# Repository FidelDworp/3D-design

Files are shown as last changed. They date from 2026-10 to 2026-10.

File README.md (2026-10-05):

# 3D-design
Ontwerp van 3D objecten in samenwerking met Claude.ai etc...

1) ROOMSENSE CAP: Kapje op de Roomsense PCB. Aaangepast aan de nieuwe 3v3 PIR sensor: Kleinere diameter, excentrisch.

Prijs gevraagd in geraardsbergen bij https://www.dilima.be/3dprint.

Offerte aangevraagd op 5 oct 26 aan: serge@dilima.be

"Hoi, ik ben Filip uit Zarlardinge en wil graag een kleine reeks 3D objecten laten maken.
Daarom graag een prijs voor dit ontwerp:

RoomSense_cap.stl

Keuzes:

- Materiaal: PETG, PLA of PLA+ (5 in ZWART, 5 in WIT)
- Laaghoogte 0,2 mm
- Printen met de rand op het bed
- Tree supports binnenin.

Laat je mij weten als je nog extra info nodig hebt aub?

Vooraf bedankt!
Filip Delannoy
0477743888"

2) ESP32_shield_cap: Het kapje is een rechthoekige doos zonder bodem. Het dekt de ESP32-C6 ZARLAR shield af, die met 4 hoekschroeven rechtstreeks op een plankje vastzit. De rand van het kapje zakt tot op het plankje. Het kapje klikt vast met taps toelopende klemnokjes op de PCB-rand en heeft geen eigen schroeven nodig.

Doorvoeren: alle doorvoeren voor kabels zitten in de zijwanden, als sleuven die onderaan open zijn. Je kunt het kapje dus over de aangesloten kabels schuiven.
Antenne: de antenne van de ESP32 steekt door een sleuf in de bovenwand naar buiten, zodat de behuizing het signaal niet hindert.
Dak: het dak is dicht, met het iTroniX-logo en de naam 0,6 mm verzonken.

3)

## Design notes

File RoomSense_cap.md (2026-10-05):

# RoomSense-kapje – ontwerpdocumentatie

| | |
|---|---|
| **Onderdeel** | 3D-geprint afdekkapje voor de RoomSenseboX v3.0 PCB (iTroniX) |
| **Versie** | v1.4 – 2026-10-05 |
| **Bronbestand** | `RoomSense_cap.scad` (OpenSCAD, volledig parametrisch) |
| **Printbestand** | `RoomSense_cap.stl` (met ingebouwde steunvinnen) |
| **PCB-referentie** | Eagle `RoomsenseboX-v3.0.brd` (export `RoomsenseboX-v3.0-brd-RD-dim.pdf`) |

## 1. Beschrijving

Het kapje dekt de RoomSenseboX-PCB af, die plat tegen het plafond of de muur geschroefd zit. De onderrand van het kapje valt samen met de onderkant van de PCB. Het kapje klemt op de PCB-rand en heeft geen eigen schroeven nodig.

Belangrijkste wijziging t.o.v. het oude (verloren) ontwerp: de grote 5 V **HC-SR501** PIR is vervangen door de kleine 3,3 V **AM312** PIR. Die zit excentrisch, vlak naast de RJ45-connector. Daardoor is de kegel **scheef**: de top met het PIR-plateau ligt boven de AM312. Aan de RJ45-kant loopt de kegel steil af, aan de overkant flauw.

### Onderdelen op de PCB die het kapje bedient

| Onderdeel | Functie in het kapje |
|---|---|
| AM312 PIR | Opening Ø 15 mm in het plateau. De lens steekt erdoor naar buiten. |
| LDR | Lichtopening Ø 10 mm |
| DS18B20-2 | Ventilatierooster Ø 10 mm erboven (luchttemperatuur) |
| DHT22 / AM2302 (T&H) | Eigen vak dat overgaat in de kegel, met een rooster van Ø 10 mm erboven |
| RJ45 | Open tunnel. De stekker blijft in de connector zitten. |
| 4 PCB-montageschroeven | Uitsparingen in de binnenrichel voor de schroefkoppen |

## 2. Assenstelsel

- **Oorsprong:** middelpunt van de PCB.
- **z = 0:** onderkant van de PCB, dus het plafond- of muurvlak.
- **Bovenaanzicht, hoeken (wijzerzin):**

| Hoek | Richting | Onderdeel |
|---|---|---|
| 0° | −Y (onder) | RJ45 |
| 90° | −X (links) | LDR |
| 270° | +X (rechts) | DHT22 |

In de code zet `upos(hoek, straal)` een hoek uit deze conventie om naar XY.

## 3. Afmetingen

### 3.1 PCB (gemeten / uit Eagle)

| Item | Waarde |
|---|---|
| PCB-diameter | 72,0 mm |
| PCB-dikte | 1,75 mm |
| Montagegaten PCB (Ø 3,2) | (27,4 ; 18,8), (−26,8 ; 18,2), (18,5 ; −27,0), (−17,9 ; −27,4), dus R ≈ 33,2 mm |
| RJ45-behuizing (Eagle) | X −8,6 … +7,0 / Y −20,0 … −38,6. Steekt 2,6 mm buiten de PCB-rand. |
| RJ45-breedte (gemeten) | 16,2 mm, midden op X = −0,8 mm |
| RJ45-hoogte incl. PCB | 16 mm |
| PIR-header (3-pin) | midden (−0,4 ; −12,0) |
| PIR-lens AM312 | Ø 12,13 mm, midden op 17,8 mm van het centrum richting RJ45 (staat schuin op de header) |
| LDR | (−26,1 ; 0), dus 90°, R 26,1 |
| DS18B20-2 | (−24,9 ; −16), dus ≈ 57°, R 29,7 |
| DHT22-header (TH) | Y −13, X 21,7 … 29,4 |
| DHT22-voetafdruk | 28 × 18 mm op 270°, symmetrisch t.o.v. de as. Binnenkant op R 15,2, buitenhoeken op de PCB-rand. |
| DHT22-hoogte incl. PCB | 10 mm |

### 3.2 Kapje

| Item | Waarde | Parameter |
|---|---|---|
| Buitendiameter | Ø 80 mm | `outer_d` |
| Wanddikte | 2,0 mm | `wall` |
| Speling (algemeen) | 0,3 mm | `clr` |
| Binnendiameter PCB-kamer | Ø 72,6 mm | `pcb_d + 2·clr` |
| Hoogte verticale rand | 7 mm vanaf onderkant PCB | `skirt_h` |
| Bovenkant plateau | 23 mm boven het PCB-oppervlak (24,75 mm vanaf onderkant) | `top_above` |
| Plateau rond PIR | Ø 21 mm, middelpunt (0 ; −17,8) | `plateau_d`, `pir_ecc` |
| PIR-opening | Ø 15 mm | `pir_hole_d` |
| LDR-opening | Ø 10 mm op 90°, R 26,1 | `ldr_hole_d`, `ldr_ang`, `ldr_r` |
| Rooster DS18B20 | Ø 10 mm op 57°, R 28 | `vent1_ang`, `vent1_r`, `vent_d` |
| Rooster DHT22 | Ø 10 mm op 270°, R 24,2 (midden van het DHT-vak) | `vent2_r` |
| Roostergaatjes | 1,2 × 1,2 mm, steek 2,0 mm | `g_hole`, `g_pitch`, `grille` |
| RJ45-tunnel, inwendig | 16,8 mm breed (16,2 + 2·0,3), 16,3 mm hoog vanaf onderkant PCB | `rj_w`, `rj_h`, `rj_off` |
| RJ45-tunnel, begin | 19,7 mm van het centrum (achterkant connector − speling) | `rj_back` |
| RJ45-tunnel, einde | Gelijk met de buitenrand van het kapje. Open naar buiten voor de stekker. | – |
| DHT22-vak, inwendig | 28,6 × radiaal tot de PCB-rand, 10,5 mm hoog vanaf onderkant PCB | `dht_len`, `dht_w`, `dht_h`, `dht_in` |
| DHT22-vak, buitenkant | Plat dak op 12,5 mm, gaat over in de kegel | – |

### 3.3 Bevestiging (klemmen zonder schroeven)

| Item | Waarde | Parameter |
|---|---|---|
| Binnenrichel | 1,5 mm breed × 1,5 mm hoog. Drukt de PCB tegen het plafond. | `ridge_w`, `ridge_h` |
| Uitsparing schroefkoppen | Ø 7 mm rond elk PCB-montagegat | `screw_head_d` |
| Klemnokjes (crush ribs) | 5 stuks op 55°, 90°, 160°, 200°, 305° | `clip_angles` |
| Profiel nokje | Driehoekig: voet 2,0 mm, punt 0,4 mm | `clip_w`, `clip_tip` |
| Indrukking in de PCB-rand | 0,35 mm | `clip_interf` |
| Invoerschuinte | 1,2 mm hoog vanaf de onderrand | `clip_lead` |

De nokjes vermijden de schroeven, de RJ45 en de hoeken van de DHT22.

### 3.4 Ingebouwde wegbreekbare steunvinnen

Aan de flauwe kant loopt de kegel maar ±20° op. Die binnenkant kan daarom niet zonder steun geprint worden. De steun zit in het model zelf, zodat de slicer **geen** support hoeft toe te voegen.

| Item | Waarde | Parameter |
|---|---|---|
| Aantal vinnen | 16, radiaal vanuit de PIR-top, gelijk verdeeld | `sup_n` |
| Hoekbereik | −40° … 220° (wiskundig, 0° = +X). De steile RJ45-kant blijft vrij. | `sup_from`, `sup_to` |
| Dikte vin | 0,8 mm (2 perimeters) | `sup_t` |
| Start / max. straal | 8 mm rond de PIR-top / 34 mm rond het PCB-midden (vrij van richel en klemnokjes) | `sup_r0`, `sup_rmax` |
| Spleet vin ↔ kegel | 0,3 mm | `sup_gap` |
| Verbinding | Tandjes van 0,8 × 0,8 mm, om de 5 mm langs de vin | `sup_tooth`, `sup_pitch` |
| Verbindingsring op het bed | Straal 14 mm rond de PIR-top, 1,2 mm breed, 0,6 mm hoog. **Raakt het kapje nergens.** | `sup_ring_r`, `sup_ring_w`, `sup_ring_h` |
| Uitgesloten zones | DHT22-vak en RJ45-tunnel | – |
| Aan / uit | `true` | `sup_on` |

**Overspanning:** tussen de vinnen is de overspanning maximaal ±15 mm, aan de buitenrand.

**Wegnemen:** het steunskelet hangt alleen via de tandjes aan de kegel, en de ring houdt de vinnen samen. Wrik het op één plaats los en trek of draai het er in één stuk uit.

Twee kleine uitzonderingen:
- **Losse vin:** de vin het dichtst bij het DHT22-vak haalt de ring niet en moet apart weg.
- **Hoek naast het DHT22-vak:** de hoek tussen het vak en de buitenrand heeft geen vin.

**Montage:** schroef eerst de PCB vast met de 4 schroeven. Druk daarna het kapje recht over de PCB tot de rand tegen het plafond zit. De RJ45-stekker kan erin blijven zitten.

## 4. Printen

| Instelling | Advies |
|---|---|
| Materiaal | PETG of PLA(+), zwart |
| Nozzle | 0,4 mm |
| Laaghoogte | 0,2 mm |
| Oriëntatie | Rand op het bed (zoals gemodelleerd) |
| Support | **Uit in de slicer.** De steunvinnen zitten in het STL-bestand (§ 3.4). |
| Gewicht / tijd (schatting) | ±15–20 g kapje + enkele gram steun, ±1,5–2 u per stuk |

**Proefprint eerst!** Controleer:
1. **Klemkracht:** zit het kapje te stroef, verlaag `clip_interf` (bv. 0,2). Zit het te los, verhoog die waarde.
2. **PIR-lens:** past de schuine lens vrij door de opening van Ø 15 mm?
3. **Hoge componenten:** blijven de LDR en de DS18B20 vrij van de binnenkant van de kegel?
4. **Steunskelet:** komt het vlot in één stuk los? Is de binnenkant tussen de vinnen netjes? Zakt het te veel door, verhoog dan `sup_n`. Breekt het te moeilijk af, verklein dan `sup_tooth` of vergroot `sup_gap`.

## 5. Aanpassen en exporteren

1. Open `RoomSense_cap.scad` in OpenSCAD.
2. Pas de parameters bovenaan het bestand aan.
3. Render met **F6** en exporteer met **File → Export → STL**.

Of via de commandoregel:

```bash
openscad -o RoomSense_cap.stl RoomSense_cap.scad
```

Werk bij elke wijziging de versiekop in het `.scad`-bestand bij, en ook de versietabel hieronder.

## 6. Versiegeschiedenis

| Versie | Datum | Wijziging |
|---|---|---|
| v1.0 | 2026-10-05 | Eerste versie: AM312 PIR (excentrisch, scheve kegel), Ø 80 mm zonder schroefgaten, klemribbels + binnenrichel, RJ45-tunnel, DHT22-vak, 2 roosters, verstevigingsringen rond LDR- en roostergat |
| v1.1 | 2026-10-05 | Verstevigingsringen verwijderd. Klemnokjes taps gemaakt: driehoekig profiel + invoerschuinte van 1,2 mm. |
| v1.2 | 2026-10-05 | Ingebouwde wegbreekbare steunvinnen onder de flauwe kegelzijde (radiaal, 0,3 mm spleet + tandjes) |
| v1.3 | 2026-10-05 | Maximaal 10 vinnen, onderaan verbonden met een losse ring op het bed, zodat het steunskelet in één stuk loskomt |
| v1.4 | 2026-10-05 | `sup_n` van 10 naar 16: overspanning tussen de vinnen ±15 mm |

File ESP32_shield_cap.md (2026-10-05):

# ESP32-shield-kapje – ontwerpdocumentatie

| | |
|---|---|
| **Onderdeel** | 3D-geprint afdekkapje voor de ESP32-C6 ZARLAR shield v2.0 (iTroniX) |
| **Versie** | v1.4 – 2026-10-05 |
| **Bronbestand** | `ESP32_shield_cap.scad` (OpenSCAD, volledig parametrisch) |
| **Logo** | `itronix_logo.svg` (moet naast het `.scad`-bestand staan) |
| **Printbestand** | `ESP32_shield_cap.stl` (logo zit er al in) |
| **PCB-referentie** | Eagle `ESP32 shield v2.0.brd` (export `ESP32_shield_v2.0_BRD.pdf`, afgedrukt op f = 2.00 → maten ÷ 2) |

## 1. Beschrijving

Het kapje is een rechthoekige doos zonder bodem. Het dekt de ESP32-C6 ZARLAR shield af, die met 4 hoekschroeven rechtstreeks op een plankje vastzit. De rand van het kapje zakt tot op het plankje. Het kapje klikt vast met taps toelopende klemnokjes op de PCB-rand en heeft geen eigen schroeven nodig.

- **Doorvoeren:** alle doorvoeren voor kabels zitten in de **zijwanden**, als sleuven die **onderaan open** zijn. Je kunt het kapje dus over de aangesloten kabels schuiven.
- **Antenne:** de antenne van de ESP32 steekt door een sleuf in de bovenwand naar buiten, zodat de behuizing het signaal niet hindert.
- **Dak:** het dak is dicht, met het **iTroniX-logo** en de naam 0,6 mm verzonken.

### Onderdelen op de PCB die het kapje bedient

| Onderdeel | Functie in het kapje |
|---|---|
| ESP32-C6 DevKitC-1 (op headers) | Vrije hoogte 19,5 mm (module + USB-C-stekker = 18 mm). Antennesleuf in de bovenwand. |
| RJ45 ROOMSENSE | Uitsparing in de rechterwand |
| RJ45 OPTIONAL | Uitsparing in de rechterwand (voor latere bestukking) |
| Power IN (schroefklem 2p) | Sleuf in de linkerwand |
| PIXEL-LINE (4p) | Sleuf in de onderwand, voor een WS2812-stick of een reep powerpixels |
| SPI/IO-header (11p) | Lange sleuf in de linkerwand |
| I2C (5p) | Sleuf in de rechterwand |
| UART (4p) | Sleuf in de bovenwand |
| T-BUS (3p) | Sleuf in de bovenwand |
| 4 hoekschroeven | Binnenhoeken krap afgerond (r 0,5 mm), zodat de schroefkoppen vrij blijven |

## 2. Assenstelsel

- **Oorsprong:** linkeronderhoek van de PCB.
- **Oriëntatie:** de tekst "ESP32-C6 ZARLAR shield" staat onderaan, de RJ45-connectoren zitten rechts en de antenne wijst naar boven.
- **z = 0:** het plankje, dus de onderkant van de PCB.

| Wand | Ligt aan | Positie langs de wand |
|---|---|---|
| Links (L) | X = 0 | Y |
| Rechts (R) | X = 79,7 | Y |
| Onder (B) | Y = 0 | X |
| Boven (T) | Y = 81,2 | X |

## 3. Afmetingen

### 3.1 PCB (uit Eagle, gemeten)

| Item | Waarde |
|---|---|
| PCB | 79,7 × 81,2 mm, dikte 1,6 mm |
| Montagegaten Ø 3,2 | (2,8 ; 2,8), (3,0 ; 78,3), (76,8 ; 2,8), (76,8 ; 78,3) |
| ESP32-C6 DevKitC-1 | 2 × 16 pins, rijen op X 17,1 en 40,0, Y 40,8 … 78,9 |
| Antenne ESP32 | X 19,6 … 37,6, steekt tot Y 86,8 (5,6 mm buiten de PCB-rand), 12–17 mm boven de PCB |
| Hoogte ESP32 + USB-C-stekker | 18 mm boven de PCB-bovenkant |
| RJ45 ROOMSENSE | Y 56,0 … 72,2 (midden 64,1), steekt 0,5 mm buiten de rechterrand |
| RJ45 OPTIONAL | Y 36,9 … 53,2 (midden 45,05) |
| RJ45-breedte / -hoogte | 16,2 mm / ±14,25 mm boven de PCB (aanname, zie §5) |
| Power IN (schroefklem, steek 5 mm) | X 6,7, Y 11,8 (+) en 16,8 (−) |
| PIXEL-LINE (GND, DO/33 Ω, 5V, 5V) | Y 3,8, X 8,9 … 16,5 |
| SPI/IO (3V3, 0, 8, 15, 23, 22, 21, 20, 9, GND + SPI CS/MOSI/MISO/SCK) | X 4,4, Y 22,5 … 53,3 |
| I2C (SCL, SDA, GND, 3V3, VCC_5V) | X 75,5, Y 14,6 … 24,8 |
| UART (GND, TX, RX, 3V3) | X 48,5, Y 71,1 … 78,8 |
| T-BUS (3V3, GND, sig) | Y 78,1, X 66,7 … 71,7 |

### 3.2 Kapje

| Item | Waarde | Parameter |
|---|---|---|
| Binnenmaat | 80,3 × 81,8 mm (PCB + 2 × 0,3 mm) | `pcb_w`, `pcb_l`, `clr` |
| Buitenmaat | **84,3 × 85,8 × 23,1 mm** | – |
| Wand- en dakdikte | 2,0 mm | `wall` |
| Speling | 0,3 mm | `clr` |
| Vrije hoogte boven PCB | 19,5 mm | `in_h` |
| Afronding buiten / binnen | r 3 mm / r 0,5 mm | `r_out`, `r_in` |
| Antennesleuf (bovenwand) | X 19,3 … 37,9, 12–17 mm boven de PCB | `ant_x`, `ant_z` |
| RJ45-uitsparingen (rechterwand) | 16,8 mm breed rond Y 64,1 en 45,05, open van onderaan tot 14,55 mm boven de PCB. Tussen beide blijft een stijltje van 2,2 mm. | `rj_yc`, `rj_w`, `rj_h` |

### 3.3 Wandsleuven

Alle sleuven zijn **onderaan open** en lopen van het plankje tot **4 mm boven de PCB-bovenkant** (parameter `slot_h`).

| Sleuf | Wand | Bereik |
|---|---|---|
| Power IN | links | Y 8,5 … 19,6 |
| SPI/IO (11p) | links | Y 21,6 … 55,1 (stijltje van 2 mm t.o.v. Power IN) |
| I2C (5p) | rechts | Y 12,8 … 26,6 |
| PIXEL-LINE (4p) | onder | X 7,4 … 18,0 |
| UART (4p) | boven | X 43,4 … 53,6 |
| T-BUS (3p) | boven | X 64,9 … 73,5 |

Je past de sleuven aan in de lijst `wall_slots` als `["wand", van, tot]`.

### 3.4 Bevestiging (klemnokjes)

| Item | Waarde | Parameter |
|---|---|---|
| Aantal | 12 (3 per wand) | – |
| Links | Y 4, 62, 75 | `clips_left` |
| Rechts | Y 6, 31, 78 | `clips_right` |
| Onder | X 30, 50, 70 | `clips_bottom` |
| Boven | X 10, 40, 59 | `clips_top` |
| Profiel | Driehoekig (crush rib): voet 2,0 mm, punt 0,4 mm | `clip_w`, `clip_tip` |
| Indrukking in de PCB-rand | 0,35 mm | `clip_interf` |
| Invoerschuinte | 1,2 mm vanaf de onderrand | `clip_lead` |
| Hoogte nokje | tot 1,5 mm boven de PCB | `clip_top` |

De nokjes vallen nergens in een sleuf of uitsparing.

**Montage:** sluit eerst alle kabels aan. Schuif daarna het kapje recht van bovenaf over de shield tot de rand op het plankje staat. De kabels glijden daarbij in de open sleuven.

### 3.5 Logo

| Item | Waarde | Parameter |
|---|---|---|
| Bestand | `itronix_logo.svg`, uit het originele Illustrator-bestand `iTroniX Logo.ai` (1200 dpi gerenderd en overgetrokken) | `logo_file` |
| Breedte × hoogte | 60 × ±51 mm | `logo_w` |
| Diepte gravure | 0,6 mm (3 lagen van 0,2 mm). Het dak blijft daaronder 1,4 mm. | `logo_depth` |
| Positie | Midden van het dak | `logo_pos` |
| Aan / uit | `true` | `logo_on` |

## 4. Printen

| Instelling | Advies |
|---|---|
| Materiaal | PETG of PLA(+), zwart |
| Nozzle | 0,4 mm |
| Laaghoogte | 0,2 mm |
| Oriëntatie | **Dak op het bed** (ondersteboven). Het verzonken logo komt dan scherp uit. |
| Support | Normaal niet nodig. De bovenkant van de antennesleuf en van de RJ45-uitsparingen zijn korte bruggen (≤ 19 mm). |

## 5. Te controleren bij de proefprint

1. **Klemkracht:** zit het kapje te stroef, verlaag `clip_interf` (bv. 0,2). Zit het te los, verhoog die waarde.
2. **RJ45-hoogte:** de aanname is 14,25 mm boven de PCB, zoals bij de RoomSense-PCB. Meet je eigen connector na.
3. **Antenne:** steekt die vrij door de sleuf van 12–17 mm?
4. **Logo:** de fijnste punten van de bliksemschichten zijn smaller dan 0,5 mm. Zijn ze dichtgelopen, verhoog dan `logo_w` naar bv. 70 mm.

## 6. Aanpassen en exporteren

1. Zet `ESP32_shield_cap.scad` en `itronix_logo.svg` in dezelfde map.
2. Open het `.scad`-bestand in OpenSCAD en pas de parameters bovenaan aan.
3. Render met **F6** en exporteer met **File → Export → STL**.

Of via de commandoregel:

```bash
openscad -o ESP32_shield_cap.stl ESP32_shield_cap.scad
```

Werk bij elke wijziging de versiekop in het `.scad`-bestand bij, en ook de versietabel hieronder.

## 7. Versiegeschiedenis

| Versie | Datum | Wijziging |
|---|---|---|
| v1.0 | 2026-10-05 | Eerste versie: doos zonder bodem, klemnokjes op 4 zijden, antennesleuf, 2 × RJ45, L-vensters voor Power IN en PIXEL-LINE, sleuven in het dak |
| v1.1 | 2026-10-05 | Alle doorvoeren naar de zijwanden verplaatst, dak volledig dicht, klemnokjes verplaatst |
| v1.2 | 2026-10-05 | Wandsleuven onderaan open, zodat het kapje over de aangesloten kabels schuift |
| v1.3 | 2026-10-05 | iTroniX-logo + naam 0,6 mm verzonken in het dak (overgetrokken van een JPG) |
| v1.4 | 2026-10-05 | Logo vervangen door een versie uit het originele `.ai`-bestand, met scherpere contouren |

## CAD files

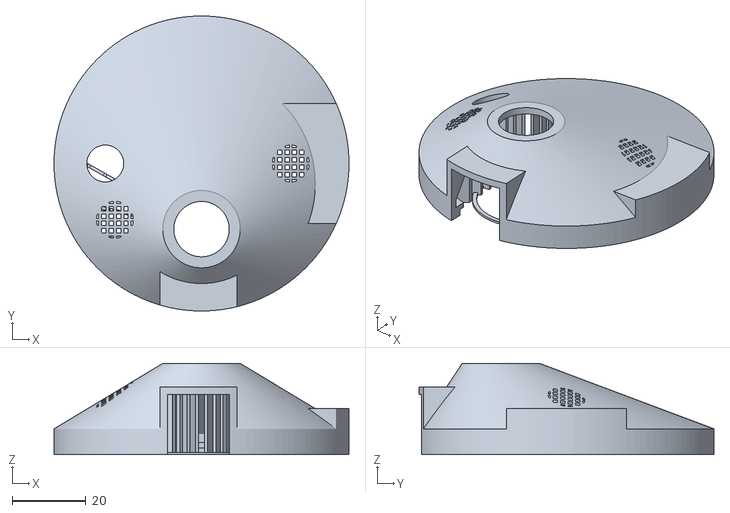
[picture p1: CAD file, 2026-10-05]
RoomSense_cap.stl
80.0 x 80.0 x 24.8

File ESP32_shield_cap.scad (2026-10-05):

// =====================================================================
// ESP32_shield_cap.scad  –  Kapje voor ESP32-C6 ZARLAR shield v2.0 (iTroniX)
// Versie : v1.4
// Datum  : 2026-10-05
// Auteur : FiDel / Claude
// Wijzigingen:
//   v1.0  Eerste versie: doos zonder bodem tot op het plankje, klemnokjes op
//         de PCB-rand (4 zijden), antennesleuf, 2x RJ45, L-vensters voor
//         Power IN en PIXEL-LINE, daksleuven voor T-BUS, UART, I2C, SPI/IO.
//   v1.1  Alle doorvoeren nu in de zijwanden (dak volledig dicht):
//         Power IN, PIXEL-LINE, T-BUS, UART, I2C en SPI/IO als sleuf
//         net boven de PCB tot slot_h hoog. Klemnokjes verplaatst.
//   v1.2  Wandsleuven onderaan open (tot op het plankje), zodat het kapje
//         over de aangesloten kabels schuift.
//   v1.3  iTroniX-logo + naam verzonken in het dak (bestand itronix_logo.svg).
//   v1.4  itronix_logo.svg vervangen door versie uit het originele .ai-bestand
//         (1200 dpi, scherpere contouren).
// ---------------------------------------------------------------------
// Assenstelsel: oorsprong = linkeronderhoek PCB (tekst "ESP32-C6 ZARLAR
//   shield" onderaan, RJ45 rechts, antenne boven), z = 0 = plankje.
//   Posities uit Eagle-layout "ESP32 shield v2.0.brd" (PDF f=2.00 -> /2).
// Printen: dak op het bed (ondersteboven), PLA/PETG, 0,4 mm nozzle.
// =====================================================================

$fn = 48;

/* [Algemeen] */
clr      = 0.3;     // speling
wall     = 2.0;     // wand- en dakdikte
pcb_w    = 79.7;    // PCB X
pcb_l    = 81.2;    // PCB Y
pcb_t    = 1.6;     // PCB dikte
in_h     = 19.5;    // vrije hoogte boven PCB (ESP32 + USB-C = 18 mm)
r_out    = 3;       // afronding buitenhoeken
r_in     = 0.5;     // afronding binnenhoeken (schroefkoppen in de hoeken!)

/* [Antenne ESP32] */
ant_x    = [19.6, 37.6];   // breedte antenne
ant_z    = [12, 17];       // sleuf boven PCB-bovenkant

/* [RJ45 rechts] */
rj_yc    = [64.1, 45.05];  // ROOMSENSE, OPTIONAL
rj_w     = 16.2;
rj_h     = 14.25;          // hoogte boven PCB

/* [Wandsleuven] */
// [wand, van, tot]  wand: "L","R","B"(onder),"T"(boven); van/tot = Y (L/R) of X (B/T)
slot_h   = 4.0;            // sleufhoogte boven PCB-bovenkant (sleuf open tot onderaan)
wall_slots = [
    ["L",  8.5, 19.6],     // Power IN (schroefklem)
    ["B",  7.4, 18.0],     // PIXEL-LINE 4p
    ["L", 21.6, 55.1],     // SPI/IO 11p (3V3 ... GND), 2 mm stijltje t.o.v. Power
    ["R", 12.8, 26.6],     // I2C 5p
    ["T", 43.4, 53.6],     // UART 4p
    ["T", 64.9, 73.5]      // T-BUS 3p
];

/* [Logo] */
logo_on    = true;
logo_file  = "itronix_logo.svg";   // moet naast dit .scad-bestand staan
logo_w     = 60;     // breedte logo in mm
logo_depth = 0.6;    // diepte gravure (3 lagen van 0,2 mm)
logo_pos   = [0, 0]; // verschuiving t.o.v. het midden van het dak

/* [Klemnokjes] */
clip_interf = 0.35;
clip_w      = 2.0;
clip_tip    = 0.4;
clip_lead   = 1.2;
clip_top    = pcb_t + 1.5;
clips_left   = [4, 62, 75];    // Y (vrij van Power IN en SPI/IO)
clips_right  = [6, 31, 78];    // Y (vrij van I2C en RJ45)
clips_bottom = [30, 50, 70];   // X (vrij van PIXEL-LINE)
clips_top    = [10, 40, 59];   // X (vrij van UART en T-BUS)

// ---------------------------------------------------------------------
pcb_top = pcb_t;
roof_z  = pcb_top + in_h;              // onderkant dak
H       = roof_z + wall;               // totale hoogte
ix0 = -clr; iy0 = -clr; ix1 = pcb_w + clr; iy1 = pcb_l + clr;   // binnenkant

module rbox(x0, y0, x1, y1, h, r)
    hull() for (x=[x0 + r, x1 - r], y=[y0 + r, y1 - r])
        translate([x, y, 0]) cylinder(r=r, h=h);

module shell()
    difference() {
        rbox(ix0 - wall, iy0 - wall, ix1 + wall, iy1 + wall, H, r_out);
        translate([0,0,-1]) rbox(ix0, iy0, ix1, iy1, roof_z + 1, r_in);
    }

// klemnokje: lokaal +X = naar binnen, op de binnenwand
module clip()
    hull() {
        translate([-0.2, -clip_w/2, 0]) cube([0.2, clip_w, clip_top]);
        translate([clr + clip_interf - 0.01, -clip_tip/2, clip_lead])
            cube([0.01, clip_tip, clip_top - clip_lead]);
    }
module clips() {
    for (y=clips_left)   translate([ix0, y, 0]) clip();
    for (y=clips_right)  translate([ix1, y, 0]) rotate([0,0,180]) clip();
    for (x=clips_bottom) translate([x, iy0, 0]) rotate([0,0,90]) clip();
    for (x=clips_top)    translate([x, iy1, 0]) rotate([0,0,-90]) clip();
}

module cutouts() {
    // antenne door bovenwand
    translate([ant_x[0] - clr, iy1 - 1, pcb_top + ant_z[0]])
        cube([ant_x[1] - ant_x[0] + 2*clr, wall + 2, ant_z[1] - ant_z[0]]);
    // RJ45 rechterwand
    for (yc=rj_yc) translate([ix1 - 1, yc - rj_w/2 - clr, -1])
        cube([wall + 2, rj_w + 2*clr, pcb_top + rj_h + clr + 1]);
    // wandsleuven, open van onderaan tot slot_h boven de PCB
    for (w=wall_slots) {
        z0 = -1; dz = pcb_top + slot_h + 1;
        if (w[0]=="L") translate([ix0 - wall - 1, w[1], z0]) cube([wall + 2, w[2] - w[1], dz]);
        if (w[0]=="R") translate([ix1 - 1,        w[1], z0]) cube([wall + 2, w[2] - w[1], dz]);
        if (w[0]=="B") translate([w[1], iy0 - wall - 1, z0]) cube([w[2] - w[1], wall + 2, dz]);
        if (w[0]=="T") translate([w[1], iy1 - 1,        z0]) cube([w[2] - w[1], wall + 2, dz]);
    }
}

module logo()
    translate([(ix0 + ix1)/2 + logo_pos[0], (iy0 + iy1)/2 + logo_pos[1], H - logo_depth])
        linear_extrude(logo_depth + 1)
            resize([logo_w, 0], auto=true) import(logo_file, center=true);

module cap() {
    difference() {
        union() { shell(); clips(); }
        cutouts();
        if (logo_on) logo();
    }
}

cap();

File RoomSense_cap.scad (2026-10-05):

// =====================================================================
// RoomSense_cap.scad  –  Kapje voor RoomSenseboX v3.0 PCB (iTroniX)
// Versie : v1.4
// Datum  : 2026-10-05
// Auteur : FiDel / Claude
// Wijzigingen:
//   v1.0  Eerste versie: AM312 PIR (excentrisch), Ø80 zonder schroefgaten,
//         klemribbels + binnenrichel, RJ45-tunnel, DHT22-vak, 2 roosters.
//   v1.1  Verstevigingsringen rond LDR- en roostergat verwijderd.
//         Klemnokjes taps: driehoekig profiel (crush rib) + lange invoerschuinte.
//   v1.2  Ingebouwde wegbreekbare steunvinnen onder de flauwe kegelzijde
//         (radiaal vanuit de PIR-top, 0,3 mm spleet + dunne tandjes).
//   v1.3  Max. 10 steunvinnen (gelijk verdeeld), onderaan verbonden met een
//         dunne ring op het bed -> steunskelet komt in een stuk los.
//   v1.4  sup_n 10 -> 16: kortere overspanning tussen de vinnen (±15 mm).
// ---------------------------------------------------------------------
// Assenstelsel (bovenaanzicht):
//   oorsprong = middelpunt PCB, z = 0 = onderkant PCB (= plafond/wand)
//   Hoeken zoals afgesproken: 0° = RJ45 (-Y), 90° = LDR (-X),
//   270° = DHT22 (+X).  Posities uit Eagle-layout RoomsenseboX-v3.0.brd
// Printen: rand op het bed, PLA/PETG, 0,4 mm nozzle, ZONDER slicer-support:
//          de steunvinnen zitten in het model (sup_on). Na het printen wegbreken.
// =====================================================================

$fn = 120;

/* [Algemeen] */
clr        = 0.3;    // speling
wall       = 2.0;    // wanddikte
pcb_d      = 72;     // PCB diameter
pcb_t      = 1.75;   // PCB dikte
outer_d    = 80;     // buitendiameter kapje
skirt_h    = 7;      // hoogte verticale rand (vanaf onderkant PCB)
top_above  = 23;     // bovenkant plateau boven PCB-oppervlak
top_z      = pcb_t + top_above;

/* [PIR AM312] */
pir_ecc    = 17.8;   // afstand middelpunt lens tot PCB-middelpunt (richting RJ45)
pir_hole_d = 15;     // opening
plateau_d  = 21;     // vlak plateau rond de opening

/* [LDR] */
ldr_ang    = 90;
ldr_r      = 26.1;
ldr_hole_d = 10;

/* [RJ45] */
rj_w       = 16.2;   // breedte connector
rj_h       = 16;     // hoogte incl. PCB (vanaf onderkant PCB)
rj_off     = -0.8;   // zijdelingse verschuiving t.o.v. de 0°-as (Eagle: X -0,8)
rj_back    = 20.0;   // afstand middelpunt -> achterkant connector

/* [DHT22] */
dht_ang    = 270;
dht_len    = 28;     // langs de rand
dht_w      = 18;     // radiaal
dht_h      = 10;     // hoogte incl. PCB
dht_in     = 15.2;   // binnenkant blokje (radiaal), hoeken op PCB-rand

/* [Ventilatie] */
vent1_ang  = 57;     // boven DS18B20-2 (≈60°)
vent1_r    = 28;
vent2_r    = dht_in + dht_w/2;  // midden boven DHT22
vent_d     = 10;
grille     = true;   // true = rooster, false = één open gat
g_hole     = 1.2;    // vierkant gaatje rooster
g_pitch    = 2.0;

/* [Bevestiging] */
clip_angles = [55, 90, 160, 200, 305];  // klemribbels (vermijdt schroeven, RJ45, DHT)
clip_interf = 0.35;  // indrukking in PCB-rand (afstellen met proefprint)
clip_w      = 2.0;    // breedte voet van het nokje
clip_tip    = 0.4;    // breedte punt van het nokje (= 1 nozzle)
clip_lead   = 1.2;    // hoogte invoerschuinte vanaf onderrand
ridge_w     = 1.5;   // binnenrichel op PCB-bovenkant
ridge_h     = 1.5;
screws      = [[27.4,18.8],[-26.8,18.2],[18.5,-27.0],[-17.9,-27.4]]; // PCB-montagegaten
screw_head_d = 7;    // vrijloop rond schroefkop

/* [Wegbreekbare steunvinnen] */
sup_on     = true;
sup_t      = 0.8;    // dikte vin (2 perimeters)
sup_gap    = 0.3;    // spleet tussen vin en kegel
sup_tooth  = 0.8;    // lengte tandje (verbinding vin <-> kegel)
sup_pitch  = 5;      // afstand tussen tandjes langs de vin
sup_n      = 16;     // aantal vinnen (gelijk verdeeld over het hoekbereik)
sup_ring_r = 14;     // straal verbindingsring rond de PIR-top (raakt enkel de vinnen)
sup_ring_w = 1.2;    // breedte ring
sup_ring_h = 0.6;    // hoogte ring (3 lagen)
sup_from   = -40;    // hoekbereik (wiskundig, 0 = +X) ...
sup_to     = 220;    // ... steile RJ45-kant (-Y) blijft vrij
sup_r0     = 8;      // vinnen starten op deze straal rond de PIR-top
sup_rmax   = 34;     // max. straal t.o.v. PCB-midden (vrij van richel en klemnokjes)

// ---------------------------------------------------------------------
function upos(a, r) = [-r*sin(a), -r*cos(a)];   // gebruikershoek -> XY
module at_angle(a) rotate([0,0,270 - a]) children(); // lokale +X = radiaal naar buiten

R  = outer_d/2;
Rp = pcb_d/2 + clr;
inner_skirt_h = 5.6;           // geeft ±2 mm wand over de kegel

module disc(d, z) translate([0,0,z]) cylinder(d=d, h=0.01);

module outer_cone()
    hull() {
        cylinder(r=R, h=skirt_h);
        translate([0,-pir_ecc,0]) disc(plateau_d, top_z - 0.01);
    }

module inner_cone()
    hull() {
        translate([0,0,pcb_t + ridge_h]) cylinder(r=R - wall, h=inner_skirt_h - pcb_t - ridge_h);
        translate([0,-pir_ecc,0]) disc(plateau_d - 1, top_z - wall - 0.01);
    }

module inner_cavity() {
    inner_cone();
    translate([0,0,-1]) cylinder(r=Rp, h=1 + pcb_t + ridge_h + 0.01); // PCB-kamer
}

// --- RJ45 tunnel ---
module rj_outer()
    intersection() {
        cylinder(r=R, h=50);
        at_angle(0) translate([rj_back - clr - wall, rj_off - rj_w/2 - clr - wall, 0])
            cube([R, rj_w + 2*(clr + wall), rj_h + clr + wall]);
    }
module rj_channel()
    at_angle(0) translate([rj_back - clr, rj_off - rj_w/2 - clr, -1])
        cube([R + 5, rj_w + 2*clr, rj_h + clr + 1]);

// --- DHT22 vak ---
module dht_outer()
    intersection() {
        cylinder(r=R, h=50);
        at_angle(dht_ang) translate([dht_in - clr - wall, -dht_len/2 - clr - wall, 0])
            cube([R, dht_len + 2*(clr + wall), dht_h + 0.5 + wall]);
    }
module dht_cavity()
    intersection() {
        translate([0,0,-1]) cylinder(r=Rp, h=50);
        at_angle(dht_ang) translate([dht_in - clr, -dht_len/2 - clr, -1])
            cube([R, dht_len + 2*clr, dht_h + 0.5 + 1]);
    }

// --- roosters / gaten ---
module vent(p) translate([p[0], p[1], -1])
    if (grille)
        intersection() {
            cylinder(d=vent_d, h=60);
            for (x=[-vent_d/2 : g_pitch : vent_d/2], y=[-vent_d/2 : g_pitch : vent_d/2])
                translate([x - g_hole/2, y - g_hole/2, 0]) cube([g_hole, g_hole, 60]);
        }
    else cylinder(d=vent_d, h=60);

// --- richel en klemribbels ---
module ridge()
    difference() {
        translate([0,0,pcb_t + 0.05]) difference() {
            cylinder(r=Rp + 0.1, h=ridge_h - 0.05);
            translate([0,0,-1]) cylinder(r=Rp - ridge_w, h=ridge_h + 2);
        }
        for (s=screws) translate([s[0], s[1], -1]) cylinder(d=screw_head_d, h=20);
    }

module clips()
    for (a=clip_angles) at_angle(a)
        hull() {
            // voet, ingebed in de wand, over de volle hoogte
            translate([Rp, -clip_w/2, 0]) cube([0.2, clip_w, pcb_t + ridge_h]);
            // punt: volle indrukking pas boven de invoerschuinte
            translate([pcb_d/2 - clip_interf, -clip_tip/2, clip_lead])
                cube([0.01, clip_tip, pcb_t + ridge_h - clip_lead]);
        }

// =====================================================================
// --- wegbreekbare steunvinnen ---
module sup_slabs()
    translate([0, -pir_ecc, 0])
        for (i=[0 : sup_n - 1]) rotate([0,0, sup_from + i*(sup_to - sup_from)/(sup_n - 1)])
            translate([sup_r0, -sup_t/2, 0]) cube([70, sup_t, 40]);

module sup_keepout()   // gebied waar geen vinnen mogen komen
    union() {
        // DHT22-vak + wanden
        at_angle(dht_ang) translate([dht_in - clr - wall - sup_gap, -dht_len/2 - clr - wall - sup_gap, -1])
            cube([R, dht_len + 2*(clr + wall + sup_gap), 50]);
        // RJ45-tunnel
        at_angle(0) translate([rj_back - clr - wall - sup_gap, rj_off - rj_w/2 - clr - wall - sup_gap, -1])
            cube([R, rj_w + 2*(clr + wall + sup_gap), 50]);
    }

module sup_area()
    difference() { cylinder(r=sup_rmax, h=50); sup_keepout(); }

module sup_fins()
    intersection() {
        sup_slabs();
        sup_area();
        union() {
            translate([0,0,-sup_gap]) inner_cone();
            cylinder(r=sup_rmax, h=pcb_t + ridge_h);   // onderste deel tot op het bed
        }
    }

module sup_teeth()
    intersection() {
        sup_slabs();
        sup_area();
        difference() { inner_cone(); translate([0,0,-sup_gap - 0.01]) inner_cone(); }
        translate([0, -pir_ecc, 0])
            for (d=[sup_r0 + 2 : sup_pitch : 70])
                difference() { cylinder(r=d + sup_tooth/2, h=40); translate([0,0,-1]) cylinder(r=d - sup_tooth/2, h=42); }
    }

module sup_ring()
    translate([0, -pir_ecc, 0]) difference() {
        cylinder(r=sup_ring_r + sup_ring_w/2, h=sup_ring_h);
        translate([0,0,-1]) cylinder(r=sup_ring_r - sup_ring_w/2, h=sup_ring_h + 2);
    }

module supports() { sup_fins(); sup_teeth(); sup_ring(); }
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

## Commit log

2026-10-05 Update README with 3D printing request details
    Added detailed request for 3D printing services including specifications and contact information.
2026-10-05 Fix formatting in README.md for material and settings
2026-10-05 Add description for ESP32 shield cap
2026-10-05 Enhance ESP32_shield_cap description in README
    Updated description of the ESP32_shield_cap to provide detailed information about its design and features.
